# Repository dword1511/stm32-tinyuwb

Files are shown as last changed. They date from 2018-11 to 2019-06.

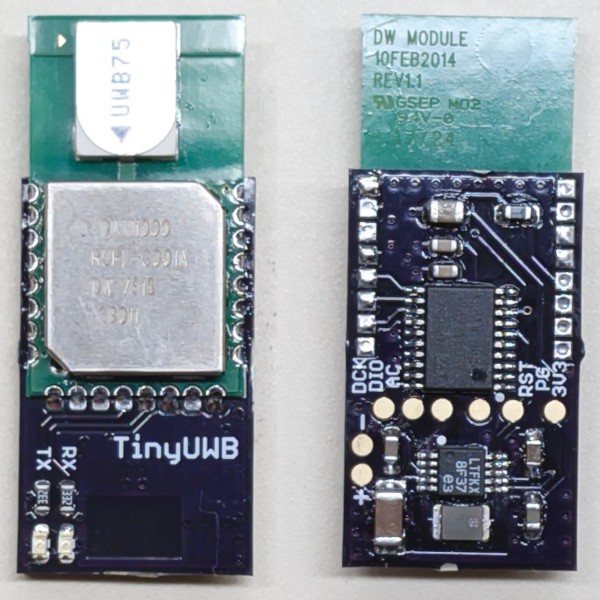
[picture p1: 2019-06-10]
pcb/pcb-photo.jpg

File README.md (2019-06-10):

# Tiny, Ultra-low-power UWB Localization Tag

This is a UWB localization tag based on Decawave `DWM1000` module and STMicro `STM32L031F6P6` ultra-low-power MCU.
The average power consumption is less than 5 mW in 6.8 Mbps mode (10 Hz update rate).

The tag has a built-in `LTC3588-1` energy harvester. WARNING: do not use `LTC3588-2`, their functionalities are very different!
The harvester can be left unpopulated and bypassed by connecting +3V3 directly to an external power source,
and then disabling the power-good logic in the source code.

## General Build Instructions

You will need the following packages (Debian/Ubuntu):

* build-essential
* gcc-arm-none-eabi
* git
* stlink-tools
* gdb-multiarch

You will have to flash and debug via the SWD test-points. Fine air-wire soldering skill required.

This project uses `libopencm3`. It will be automatically checked out during the building process.
To build the firmware, run `make`. To flash it, connect the board to a ST-Link, and then run `make flash`.
Alternatively, you can use `openocd` and any SWD debugger you fancy.

## Publication

This project was part of the following work. Please kindly consider citing the paper as shown:

```
@inproceedings{Capttery,
 author = {Zhang, Chi and Kumar, Sidharth and Bharadia, Dinesh},
 title = {{Capttery: Scalable Battery-like Room-level Wireless Power}},
 booktitle = {Proc. of ACM MobiSys},
 year = {2019},
}
```

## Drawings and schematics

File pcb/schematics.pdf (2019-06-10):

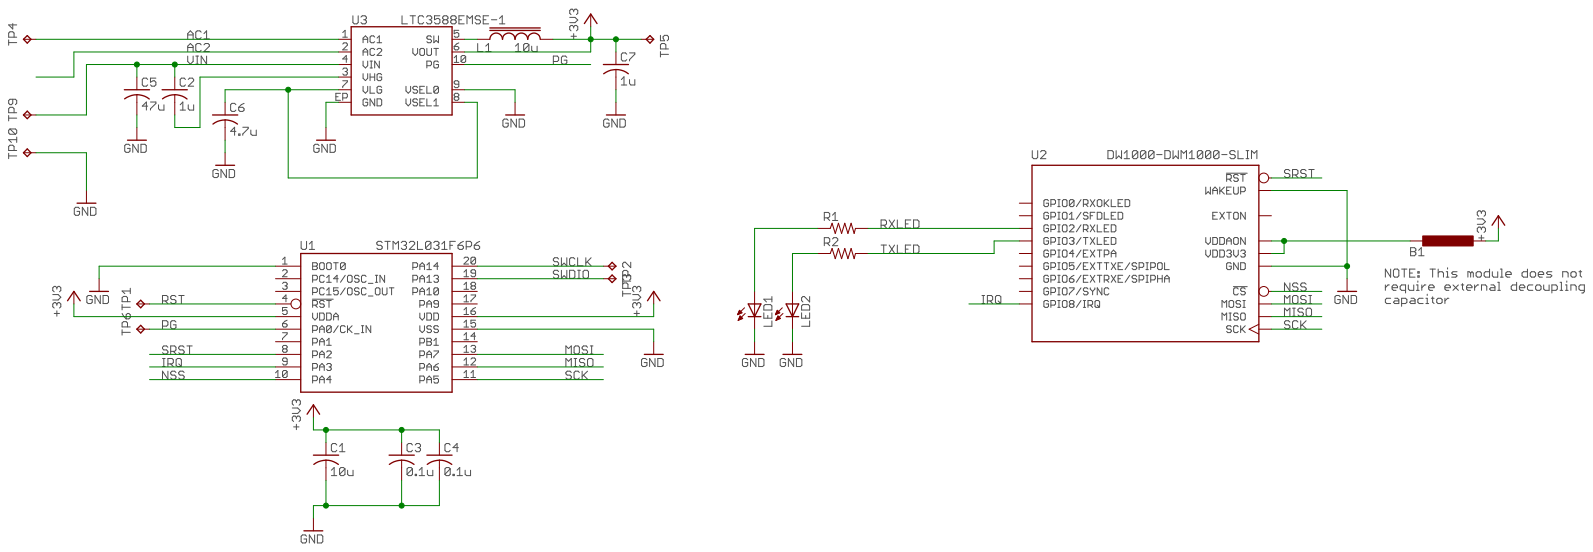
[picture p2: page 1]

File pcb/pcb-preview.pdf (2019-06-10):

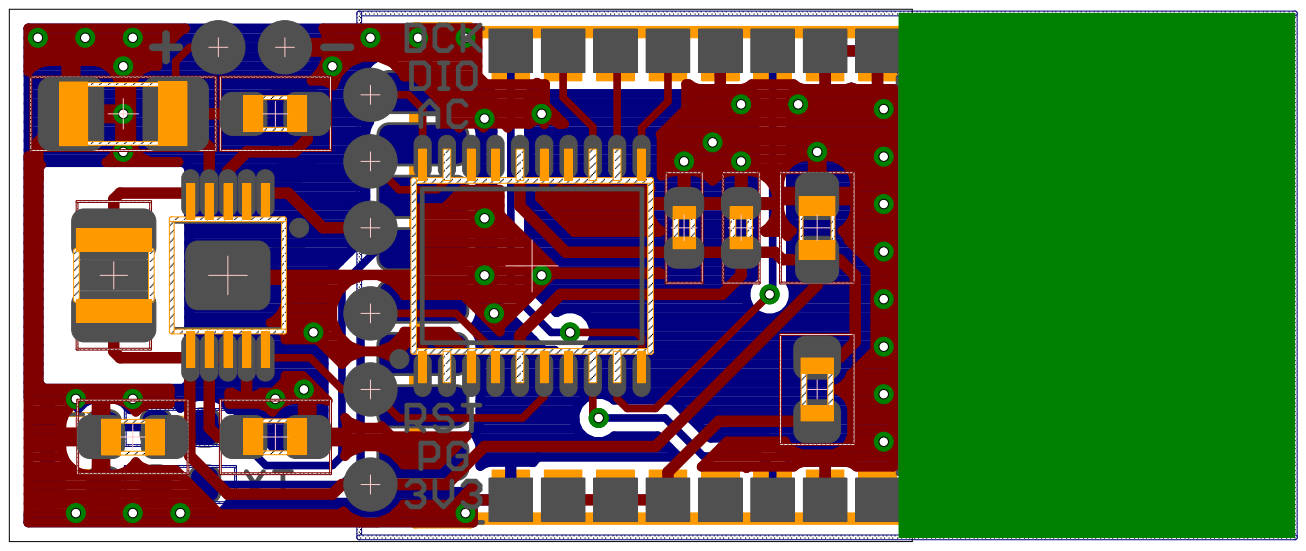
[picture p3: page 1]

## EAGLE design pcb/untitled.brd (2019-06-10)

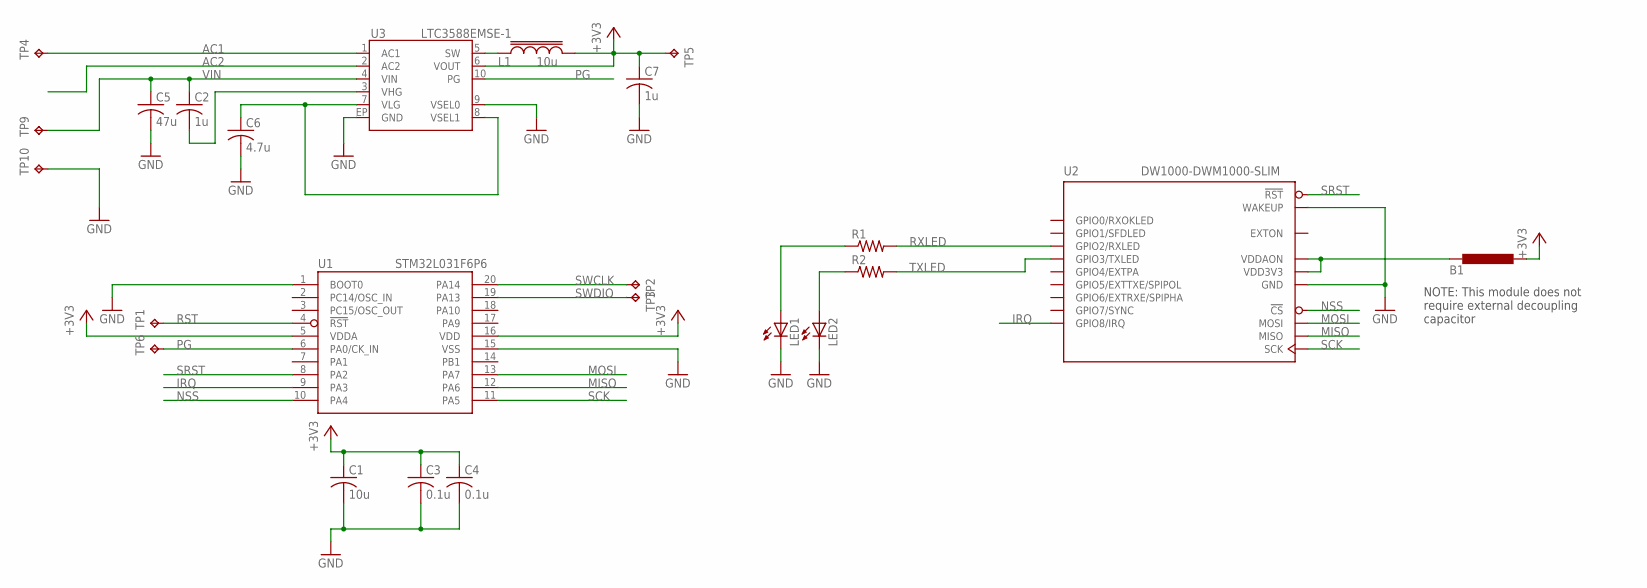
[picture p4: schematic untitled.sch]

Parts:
B1: BEAD-0603; 0603
C1: 10u; C0603
C2, C7: 1u; C0603
C3, C4: 0.1u; C0402
C5: 47u; C1206
C6: 4.7u; C0603
L1: 10u; 1008
LED1, LED2: LEDSML0603; SML0603
R1, R2: R-US_R0402; R0402
TP1, TP2, TP3, TP4, TP5, TP6, TP9, TP10: TPB1,27; B1,27
U1: STM32L031F6P6; TSSOP-20
U2: DW1000-DWM1000-SLIM
U3: LTC3588EMSE-1; MSOP-10-3X3-EP

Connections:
+3V3: B1.2, C1.1, C3.1, C4.1, C7.1, L1.2, TP5.TP, U1.5 (VDDA), U1.16 (VDD), U3.6 (VOUT)
AC1: TP4.TP, U3.1 (AC1)
AC2: U3.2 (AC2)
GND: C1.2, C3.2, C4.2, C5.2, C6.2, C7.2, LED1.C, LED2.C, TP10.TP, U1.1 (BOOT0), U1.15 (VSS), U2.2 (WAKEUP), U2.8 (GND), U2.16 (GND), U2.21 (GND), U2.23 (GND), U2.24 (GND), U3.9 (VSEL0), U3.EP (GND)
IRQ: U1.9 (PA3), U2.22 (GPIO8/IRQ)
MISO: U1.12 (PA6), U2.19 (MISO)
MOSI: U1.13 (PA7), U2.18 (MOSI)
unnamed: LED2.A, R2.1
unnamed: LED1.A, R1.1
unnamed: L1.1, U3.5 (SW)
unnamed: B1.1, U2.5 (VDDAON), U2.6 (VDD3V3), U2.7 (VDD3V3)
unnamed: C2.2, U3.3 (VHG)
unnamed: C6.1, U3.7 (VLG), U3.8 (VSEL1)
NSS: U1.10 (PA4), U2.17 (!CS)
PG: TP6.TP, U1.6 (PA0/CK_IN), U3.10 (PG)
RST: TP1.TP, U1.4 (!RST!)
RXLED: R1.2, U2.13 (GPIO2/RXLED)
SCK: U1.11 (PA5), U2.20 (SCK)
SRST: U1.8 (PA2), U2.3 (!RST)
SWCLK: TP2.TP, U1.20 (PA14)
SWDIO: TP3.TP, U1.19 (PA13)
TXLED: R2.2, U2.12 (GPIO3/TXLED)
VIN: C2.1, C5.1, TP9.TP, U3.4 (VIN)

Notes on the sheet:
NOTE: This module does not require external decoupling capacitor

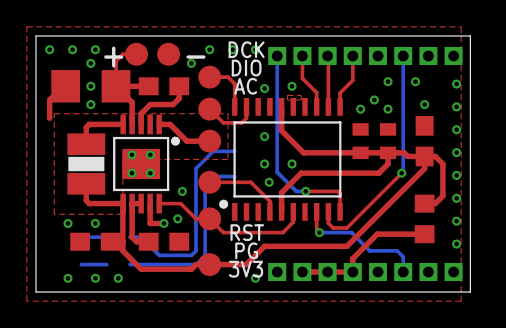
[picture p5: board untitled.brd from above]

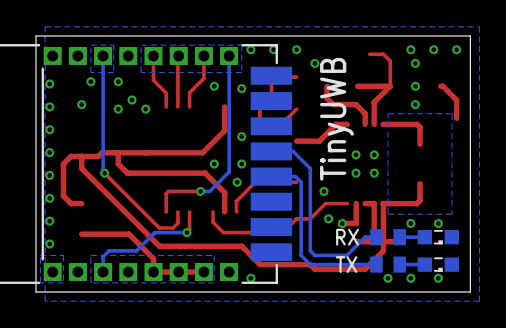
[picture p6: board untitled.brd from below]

Board: 2 copper layers, 24.1 x 14.2 mm, 24 parts (5 on the bottom side), 22 nets.

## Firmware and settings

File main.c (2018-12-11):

#include <string.h>

#include <libopencm3/cm3/nvic.h>

#include <libopencm3/stm32/gpio.h>
#include <libopencm3/stm32/spi.h>
#include <libopencm3/stm32/rcc.h>
#include <libopencm3/stm32/exti.h>

#include <os/os.h>

#include <decadriver/deca_device_api.h>

#include <decartls/instance.h>


/* NOTE: we only use GPIOA */
#define DECA_IRQ_PIN    GPIO3
#define DECA_IRQ_EXTI   EXTI3
#define DECA_IRQ        NVIC_EXTI2_3_IRQ
#define DECA_IRQ_ISR    exti2_3_isr

#define DECA_RST_PIN    GPIO2

#define LTC_PG_PIN      GPIO0

#define DECA_NODE_MODE  1 /* Mode 0 has lower power than mode 1 according to datasheet, but mode 1 consumes much less energy */
#define DECA_NODE_ADDR  0x00

/* NOTE: although BSS is only around 1KB, the application needs quite some stack for packet handling. Minimum requirement would be a STM32L031 */


static const instanceConfig_t iconfig = {
#if DECA_NODE_MODE == 0
  /* TREK1000 mode 1 */
  .channelNumber  = 2,
  .preambleCode   = 4,
  .pulseRepFreq   = DWT_PRF_16M,
  .dataRate       = DWT_BR_110K,
  .preambleLen    = DWT_PLEN_1024,
  .pacSize        = DWT_PAC32,
  .nsSFD          = 1,
  .sfdTO          = 1025 + 64 - 32,
#else
  /* TREK1000 mode 2 */
  .channelNumber  = 2,
  .preambleCode   = 4,
  .pulseRepFreq   = DWT_PRF_16M,
  .dataRate       = DWT_BR_6M8,
  .preambleLen    = DWT_PLEN_128,
  .pacSize        = DWT_PAC8,
  .nsSFD          = 0,
  .sfdTO          = 129 + 8 - 8,
#endif
};

static const sfConfig_t sconfig = {
#if DECA_NODE_MODE == 0
  /* TREK1000 mode 1 */
  .slotDuration_ms        = 28,
  .numSlots               = 10,
  .sfPeriod_ms            = 10 * 28, /* Localization rate */
  .tagPeriod_ms           = 10 * 28,
  .pollTxToFinalTxDly_us  = 20000
#else
  /* TREK1000 mode 2 */
  .slotDuration_ms        = 10,
  .numSlots               = 10,
  .sfPeriod_ms            = 10 * 10, /* Localization rate */
  .tagPeriod_ms           = 10 * 10,
  .pollTxToFinalTxDly_us  = 2700, /* Was 2500, slacked a bit (should not exceed 5000). Debug with 'b instance_tag.c:244' */
#endif
};

static dwt_local_data_t dw1000local;
static instance_data_t  instance;


/* Wake-up is triggered when NSS driven low (here by enabling SPI), but oscillator needs 5ms to stabilize. */
static void __attribute__((unused)) wakeup_chip(void) {
  spi_enable(SPI1);
  tick_sleep(1);
  spi_disable(SPI1);
  tick_sleep(7);
}

/* DW1000 mode 0, < 3 MHz before PLL lock, < 20 MHz after PLL lock */
/* Always run SPI as fast as we can, tune system clock instead to conserve power */
/* TODO: FIFO and interrupts (but libopencm3 do not sleep during SPI operation anyways) */
static void spi_setup(unsigned clk_div) {
  rcc_periph_clock_enable(RCC_SPI1);
  spi_reset(SPI1);
  spi_init_master(SPI1, clk_div, SPI_CR1_CPOL_CLK_TO_0_WHEN_IDLE, SPI_CR1_CPHA_CLK_TRANSITION_1, SPI_CR1_DFF_8BIT, SPI_CR1_MSBFIRST);
  spi_disable_software_slave_management(SPI1);
  spi_enable_ss_output(SPI1);
  spi_disable_crc(SPI1);
  spi_set_full_duplex_mode(SPI1);
  spi_set_unidirectional_mode(SPI1);
  spi_set_dff_8bit(SPI1);
}

static void wait_pgood(void) {
  rcc_periph_clock_enable(RCC_GPIOA);
#if 1
  while (!gpio_get(GPIOA, LTC_PG_PIN)) {
    asm("wfi");
  }
#else
  /* For debugging start-up process power consumption */
  while (tick_get_uptime() < 2000);
#endif
  rcc_periph_clock_disable(RCC_GPIOA);
}


int main(void) {
  os_init(); /* NOTE: system clock is now 4MHz */

  rcc_periph_clock_enable(RCC_GPIOA);

  /* NOTE: DW1000 still consumes 4mA even when RST driven down. Needs to enter deep sleep ASAP by finishing instance_init(). */

  gpio_mode_setup(GPIOA, GPIO_MODE_INPUT, GPIO_PUPD_PULLDOWN, DECA_IRQ_PIN); /* TODO: use external pull-down with higher resistance? may not help much */
  nvic_set_priority(DECA_IRQ, 60);
  nvic_enable_irq(DECA_IRQ);
  exti_select_source(DECA_IRQ_EXTI, GPIOA);
  exti_set_trigger(DECA_IRQ_EXTI, EXTI_TRIGGER_RISING);
  exti_enable_request(DECA_IRQ_EXTI);

  gpio_set_af(GPIOA, GPIO_AF0, GPIO4 | GPIO5 | GPIO6 | GPIO7);
  gpio_set_output_options(GPIOA, GPIO_OTYPE_PP, GPIO_OSPEED_25MHZ, GPIO4 | GPIO5 | GPIO6 | GPIO7);
  gpio_mode_setup(GPIOA, GPIO_MODE_AF, GPIO_PUPD_NONE, GPIO4 | GPIO5 | GPIO6 | GPIO7);

  gpio_mode_setup(GPIOA, GPIO_MODE_INPUT, GPIO_PUPD_NONE, LTC_PG_PIN);
  //rcc_periph_clock_disable(RCC_GPIOA); /* wait_pgood() does this for us */

  dwt_setdevicedataptr(&dw1000local);
  spi_setup(SPI_CR1_BAUDRATE_FPCLK_DIV_2);
  /*
  wakeup_chip();
  if (DWT_DEVICE_ID != instance_readdeviceid()) {
    os_panic();
  }
  */
  dwt_softreset(); /* Clear sleep bit if any, as good as hardware reset in most cases */
  if (instance_init() != 0) {
    os_panic();
  }
  instance_set_16bit_address(DECA_NODE_ADDR);
  instance_config(&iconfig, &sconfig);
#if DEEP_SLEEP == 1
  tag_run(); /* Run once to complete tag INIT and enter deep sleep */
#endif

  rcc_periph_clock_disable(RCC_SPI1); /* Shouldn't have communication for a while */

  wait_pgood();
  os_dvfs_hsi16();

  while (true) {
    wait_pgood();

    rcc_periph_clock_enable(RCC_SPI1);
    exti_enable_request(DECA_IRQ_EXTI);
    do {
      tag_run();
    } while (instance.testAppState != TA_SLEEP_DONE);
    exti_disable_request(DECA_IRQ_EXTI); /* Make sure nothing interrupts sleep :) */
    rcc_periph_clock_disable(RCC_SPI1);

    os_pm_sleep_until(instance.instanceWakeTime_ms + instance.tagPeriod_ms - 1);
  }

  return 0;
}

/* Implementations of low-level deca_device_api */

static void spi_rx(uint32_t spi, uint8_t *rxbuf, uint32_t len) {
  uint32_t i;

  for (i = 0; i < len; i ++) {
    rxbuf[i] = spi_xfer(spi, 0x00); /* Need to feed to get */
  }
}

static void spi_tx(uint32_t spi, const uint8_t *txbuf, uint32_t len) {
  uint32_t i;

  for (i = 0; i < len; i ++) {
    spi_xfer(spi, txbuf[i]); /* One in, one out. Read it is critical, even if it is garbage. */
  }
  return;
}

/* A bit different from spi_clean_disable() */
static void spi_disable_after_io(uint32_t spi) {
  while (!(SPI_SR(spi) & SPI_SR_TXE));
  while (SPI_SR(spi) & SPI_SR_BSY);
  SPI_CR1(spi) &= ~SPI_CR1_SPE;
}

int writetospi(uint16 headerLength, const uint8 *headerBuffer, uint32 bodylength, const uint8 *bodyBuffer) {
  spi_enable(SPI1);
  spi_tx(SPI1, headerBuffer, headerLength);
  spi_tx(SPI1, bodyBuffer, bodylength);
  spi_disable_after_io(SPI1);

  return DWT_SUCCESS;
}

int readfromspi(uint16 headerLength, const uint8 *headerBuffer, uint32 readlength, uint8 *readBuffer) {
  spi_enable(SPI1);
  spi_tx(SPI1, headerBuffer, headerLength);
  spi_rx(SPI1, readBuffer, readlength);
  spi_disable_after_io(SPI1);

  return DWT_SUCCESS;
}

/* Does not seem to be useful */
decaIrqStatus_t decamutexon(void) {
  //exti_disable_request(DECA_IRQ_EXTI);
  return 0;
}

void decamutexoff(__attribute__((unused)) decaIrqStatus_t s) {
  //exti_enable_request(DECA_IRQ_EXTI);
}

void deca_sleep(unsigned int time_ms) {
  tick_sleep(time_ms);
}

/* Implementations of deca_rtls_port */

void port_wakeup_dw1000_fast(void) {
  spi_enable(SPI1);
  tick_sleep(1);
  spi_disable(SPI1);
  tick_delay_us(35);
}

instance_data_t* instance_get_local_structure_ptr(__attribute__((unused)) unsigned int x) {
  return &instance;
}


/* IRQ handler */
void DECA_IRQ_ISR(void) {
  exti_reset_request(DECA_IRQ_EXTI);
  dwt_isr();
}

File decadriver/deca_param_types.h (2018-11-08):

/*! ----------------------------------------------------------------------------
 *  @file    deca_param_types.h
 *  @brief   Decawave general type definitions for configuration structures
 *
 * @attention
 *
 * Copyright 2013 (c) Decawave Ltd, Dublin, Ireland.
 *
 * All rights reserved.
 *
 */
#ifndef _DECA_PARAM_TYPES_H_
#define _DECA_PARAM_TYPES_H_

#ifdef __cplusplus
extern "C" {
#endif
#include "deca_types.h"

#define NUM_BR 3
#define NUM_PRF 2
#define NUM_PACS 4
#define NUM_BW 2            //2 bandwidths are supported
#define NUM_SFD 2           //supported number of SFDs - standard = 0, non-standard = 1
#define NUM_CH 6            //supported channels are 1, 2, 3, 4, 5, 7
#define NUM_CH_SUPPORTED 8  //supported channels are '0', 1, 2, 3, 4, 5, '6', 7
#define PCODES 25           //supported preamble codes


typedef struct {
    uint32 lo32;
    uint16 target[NUM_PRF];
} agc_cfg_struct ;

extern const agc_cfg_struct agc_config ;

//SFD threshold settings for 110k, 850k, 6.8Mb standard and non-standard
extern const uint16 sftsh[NUM_BR][NUM_SFD];

extern const uint16 dtune1[NUM_PRF];

#define XMLPARAMS_VERSION   (1.17f)

extern const uint32 fs_pll_cfg[NUM_CH];
extern const uint8 fs_pll_tune[NUM_CH];
extern const uint8 rx_config[NUM_BW];
extern const uint32 tx_config[NUM_CH];
extern const uint8 dwnsSFDlen[NUM_BR]; //length of SFD for each of the bitrates
extern const uint32 digital_bb_config[NUM_PRF][NUM_PACS];
extern const uint8 chan_idx[NUM_CH_SUPPORTED];
extern const float txpwr_compensation[NUM_CH];

#define PEAK_MULTPLIER  (0x60) //3 -> (0x3 * 32) & 0x00E0
#define N_STD_FACTOR    (13)
#define LDE_PARAM1      (PEAK_MULTPLIER | N_STD_FACTOR)

#define LDE_PARAM3_16 (0x1607)
#define LDE_PARAM3_64 (0x0607)

#define MIXER_GAIN_STEP (0.5)
#define DA_ATTN_STEP    (2.5)

extern const uint16 lde_replicaCoeff[PCODES];

#ifdef __cplusplus
}
#endif

#endif

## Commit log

2018-12-11 halfway fix startup bug
    [main.c]
2018-12-11 currently startup consumes 500uC
2019-06-10 add doc
    [untitled.brd, untitled.sch]
